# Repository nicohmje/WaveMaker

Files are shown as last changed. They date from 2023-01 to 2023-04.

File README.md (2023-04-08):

# Wave Generator for TECQUIPMENT FC80-5

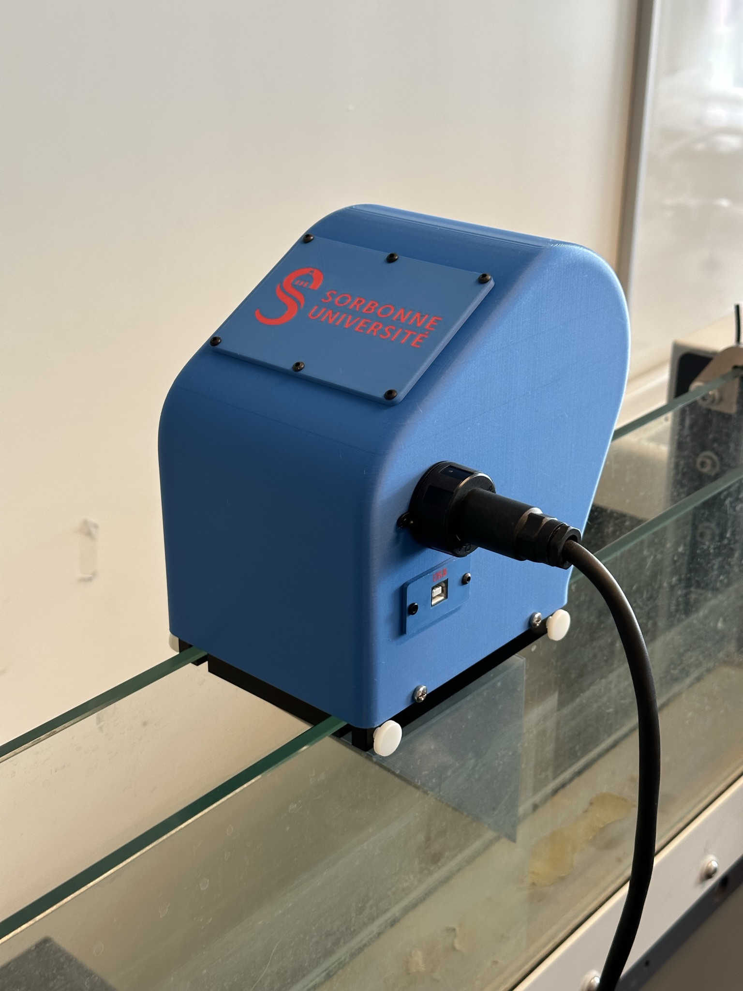
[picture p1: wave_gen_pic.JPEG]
the complete assembly


Add-on accessory designed for the TECQUIPMENT 5 meter Flow and sediment transport channel.

Intended use is to simulate various waves, including rogue waves, which are chosen by the user through a computer or a Raspberry Pi. 

Mechanical design inspired by the FC80N Wave Generator, but using two Dynamixel XL330-M288 servos and 3D printed parts. 

## Design / CAD  

First, the FC80-5 is measured, and the different parameters are defined. Chosen amplitude entails a 4 cm crankshaft, and the overall speed and responsiveness required makes the XL330-M288 the perfect motors for this use case. 

The existing FC80N is modeled, and the decision is made to keep the base and shaft bushing as they are machined aluminum which gives a nice heft that 3D printed parts wouldn't have. This significantly improves stability when displacing water. The use of the existing shaft bushing limits the shaft to a 20 cm diameter.

### 1. Bearings

The original design's joints use simple metal bushings for the pivots. The ensuing friction requires a lot of torque to smoothly overcome; this limits speed and requires a powerful motor with a significant amount of reduction (148:1 on the FC80N). Because Dynamixel Servos are to be used, all pivots will utilize ball bearings to smoothen motion and reduce motor load. 

Availability and price of bearings are a key factor in their selection; standard skateboard bearings can be found used for free in any skateboarding-related shop, and a smaller MR105-2RS bearing is used when the former don't fit. For the shaft linear motion, the original aluminum bushing provides a low enough friction coefficient that, with the right tolerance, the shaft slides smoothly back and forth with minimal side-to-side play.

### 2. 3D Printing

Every part is printed in PLA, as strength is not an issue at this scale. The shaft is printed vertically, which could lead to delamination of the layers in case of high tensile forces, but this has not been observed yet. If that were to be the case, a solution would be to print two shaft halves and glue them together. This would require support material for the joint-shaft inteface, which can increase friction because of poor surface finish. 

The plunger is printed with 10% infill to lighten it as much as possible. Possible upgrades include add-on surfaces to push the water more efficiently / in different ways. 

## Assembly

Every part fits together nicely. The U2D2 cables that go all the way to the servos don't have any routing guides, which could be added to the motor mount, as it must be ensured that they do not interfere with the crankshaft, which could lead to catastrophic tangles. 

The servos are held in place by screws, but a lack of the right sized screw prevents the crankshaft from being bolted to the motors; they are friction fitted, which works well but requires good alignment to work reliably. The plunger and shaft interface nicely with each other, with some light sanding done to the latter to improve surface finish.

## Equations

Inverse kinematics (wave -> motor pos) have not been established (yet). For future reference, these papers should help : 

B. Sun, C. Li, S. Yang, and H. Zhang, “A simplified method and numerical simulation for wedge-shaped plunger wavemaker,”

T. Mikkola, “Time accurate simulation of a plunger type wave maker using unstructured finite volume solver with surface tracking,”

C. Hirt and B. Nichols, “Volume of fluid (vof) method for the dynamics of free boundaries,”

B. Sun, C. Li, S. Yang, and H. Zhang, “A simplified method and numerical simulation for wedge-shaped plunger wavemaker,”

## Testing

TODO: Writeup about tests

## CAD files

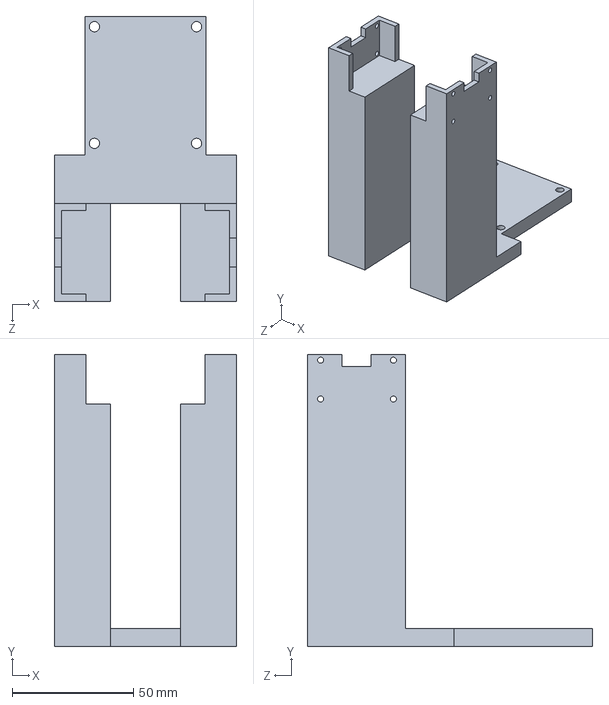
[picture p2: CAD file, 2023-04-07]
WaveMaker_CAD/WM_WaveMaker_MainFrame.SLDPRT
75.0 x 120.4 x 117.4 mm

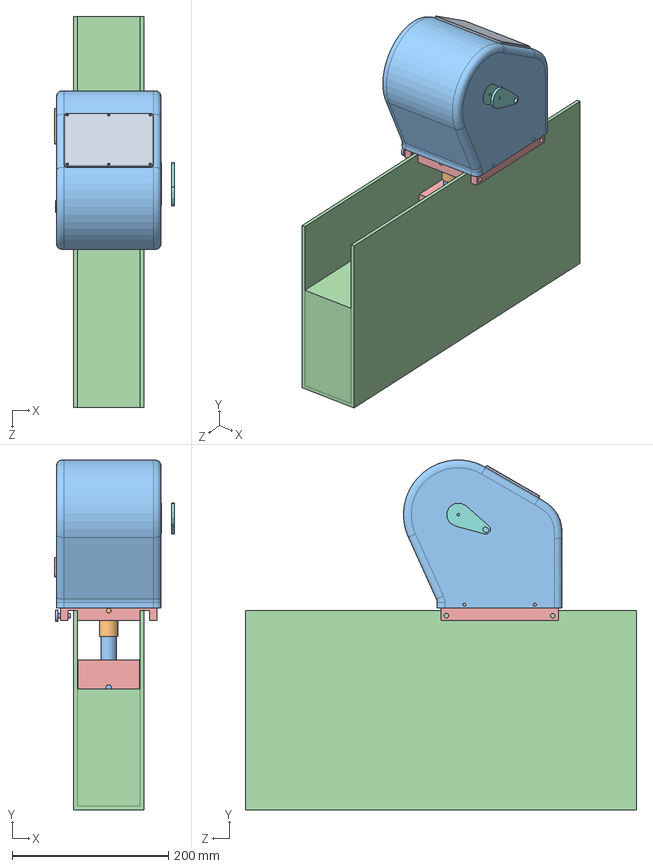
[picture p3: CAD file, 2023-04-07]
WaveMaker_CAD/WaveMaker_ASSEMBLY.SLDASM
153.7 x 447.4 x 500.0 mm
WM_WaveMaker_wave_flume
WM_WaveMaker_base
WM_WaveMaker_base_screw
WM_WaveMaker_MainFrame
WM_WaveMaker_Crankshaft_left_01 x 2
WM_WaveMaker_Joint_003
WM_WaveMaker_shaft_bushing
WM_WaveMaker_Piston_Shaft
WM_WaveMaker_Shaft
WM_WaveMaker_Plunger_002
WM_WaveMaker_Hull
WM_WaveMaker_USB-B_Mount
WM_WaveMaker_Hull_Lid
WM_WaveMaker_U2D2 Spacer x 4
WM_WaveMaker_XL330-M288T x 2
WM_WaveMaker_ROBOTIS_U2D2_Power_Hub_Board
WM_WaveMaker_SkateboardBearing
WM_WaveMaker_5_10_4

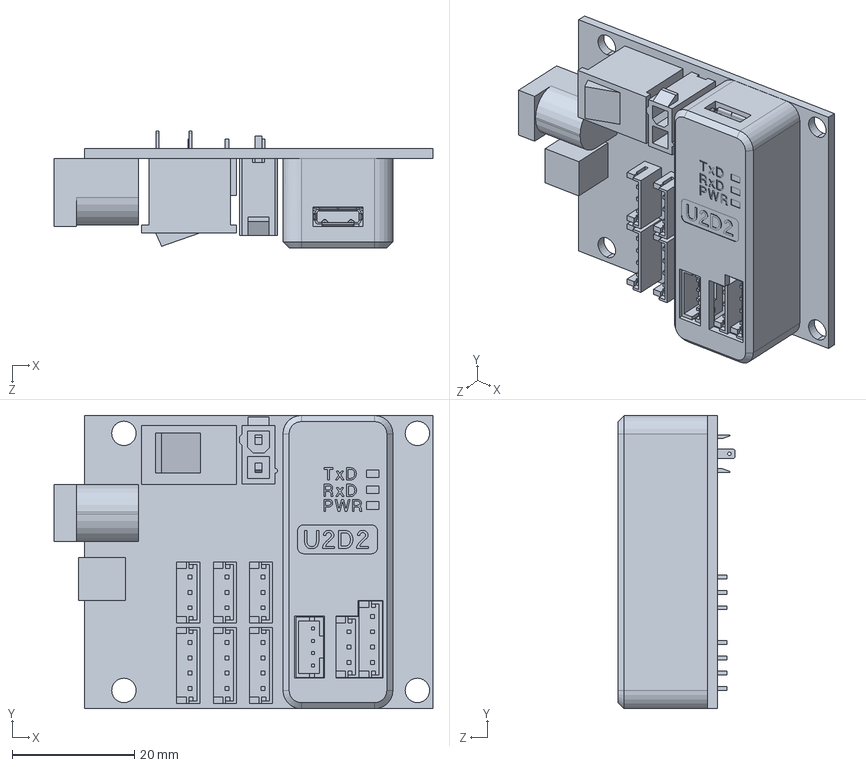
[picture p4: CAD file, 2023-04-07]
WaveMaker_CAD/WM_WaveMaker_ROBOTIS_U2D2_Power_Hub_Board.SLDPRT
62.0 x 48.0 x 19.1 mm

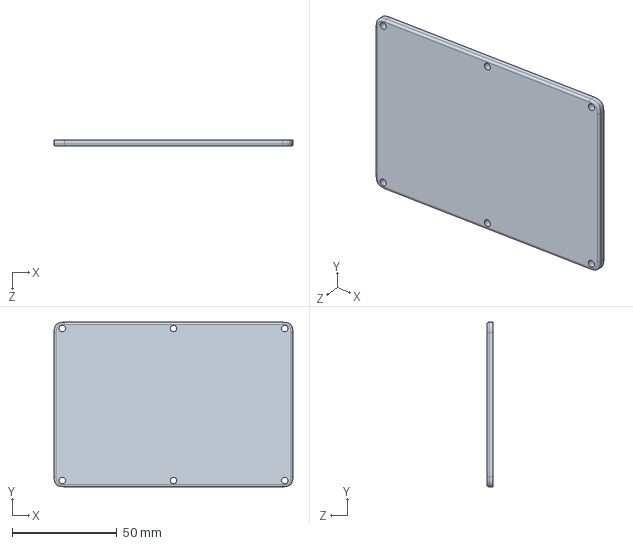
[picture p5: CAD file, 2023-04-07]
WaveMaker_CAD/WM_WaveMaker_Hull_Lid.SLDPRT
114.0 x 78.5 x 3.00 mm

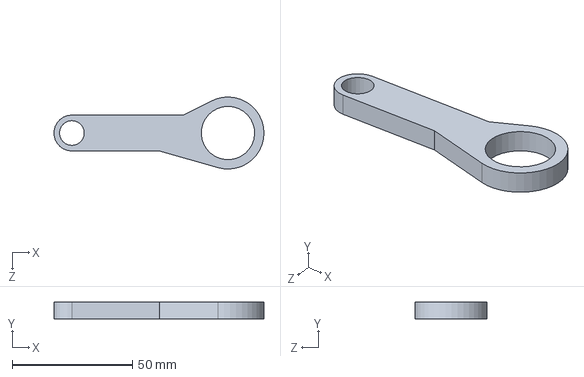
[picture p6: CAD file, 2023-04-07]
WaveMaker_CAD/WM_WaveMaker_Joint_003.SLDPRT
87.4 x 7.00 x 30.0 mm

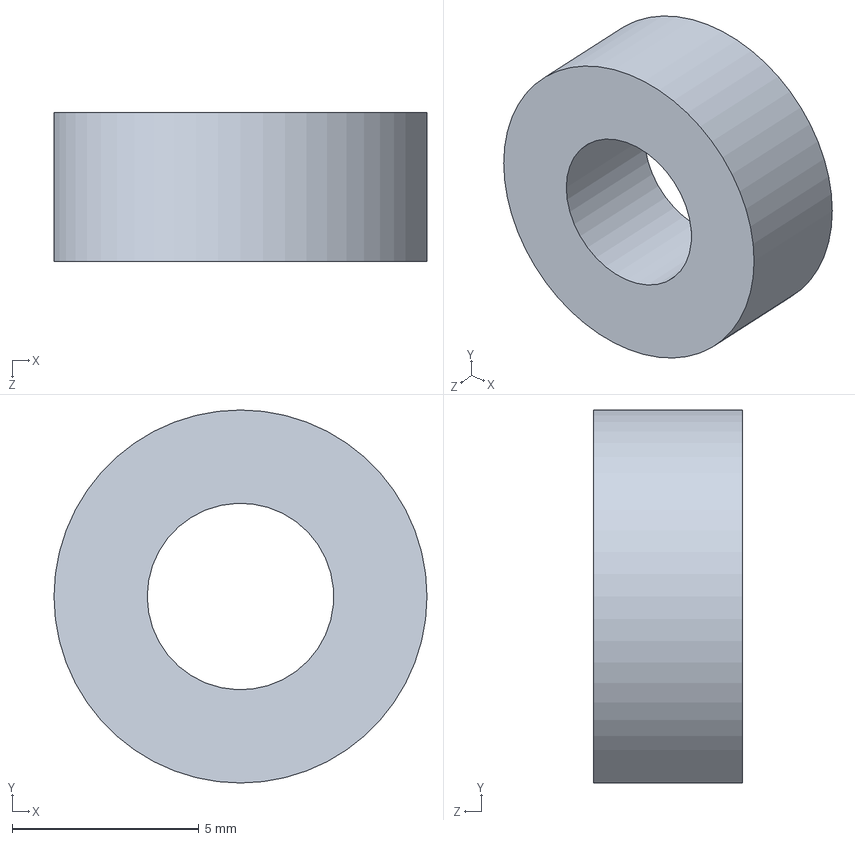
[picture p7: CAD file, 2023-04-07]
WaveMaker_CAD/WM_WaveMaker_5_10_4.SLDPRT
10.0 x 10.0 x 4.00 mm

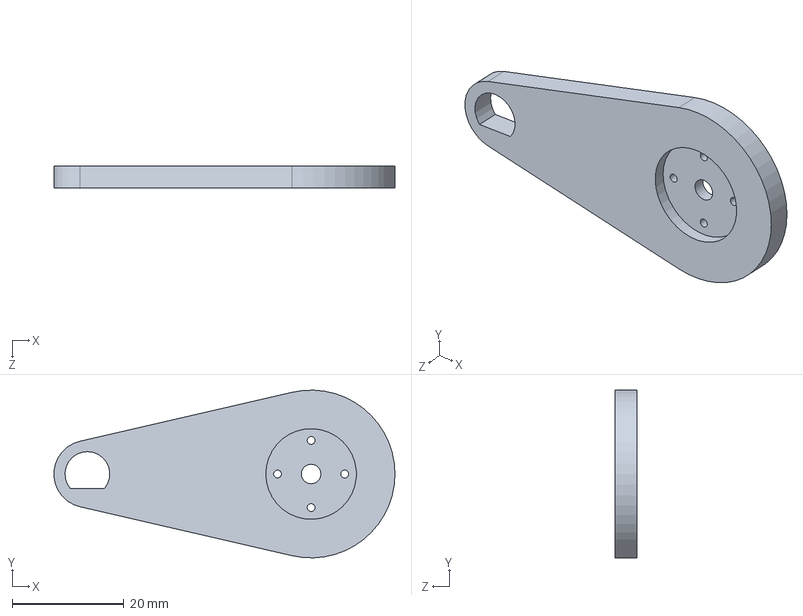
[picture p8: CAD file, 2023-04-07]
WaveMaker_CAD/WM_WaveMaker_Crankshaft_left_01.SLDPRT
61.0 x 30.0 x 4.00 mm

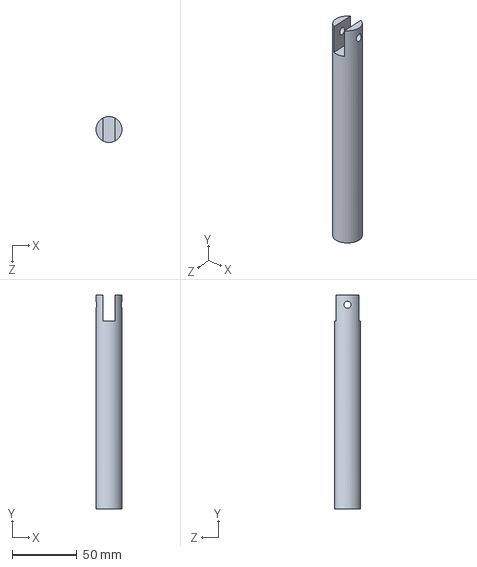
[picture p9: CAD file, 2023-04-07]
WaveMaker_CAD/WM_WaveMaker_Piston_Shaft.SLDPRT
20.0 x 165.0 x 20.0 mm

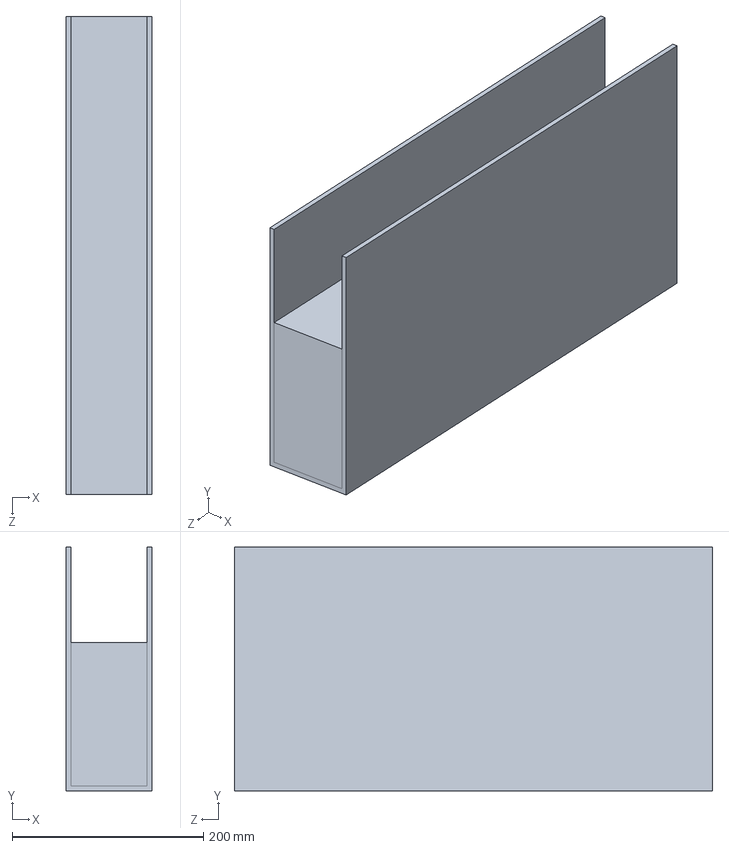
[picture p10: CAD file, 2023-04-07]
WaveMaker_CAD/WM_WaveMaker_wave_flume.SLDPRT
90.0 x 255.0 x 500.0 mm

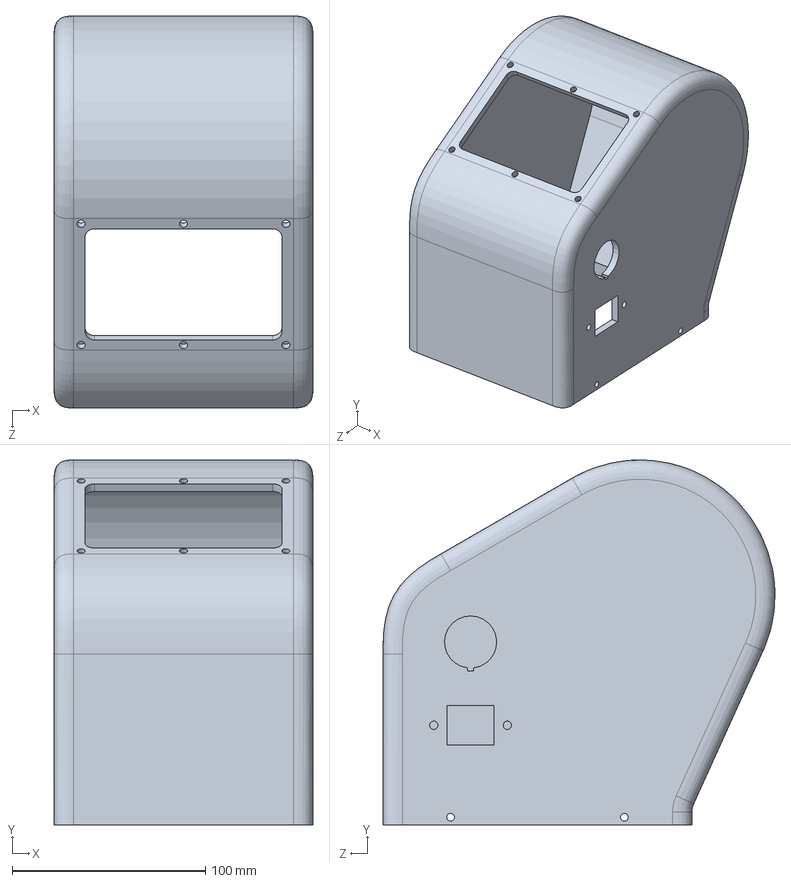
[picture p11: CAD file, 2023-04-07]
WaveMaker_CAD/WM_WaveMaker_Hull.SLDPRT
134.0 x 188.9 x 203.0 mm

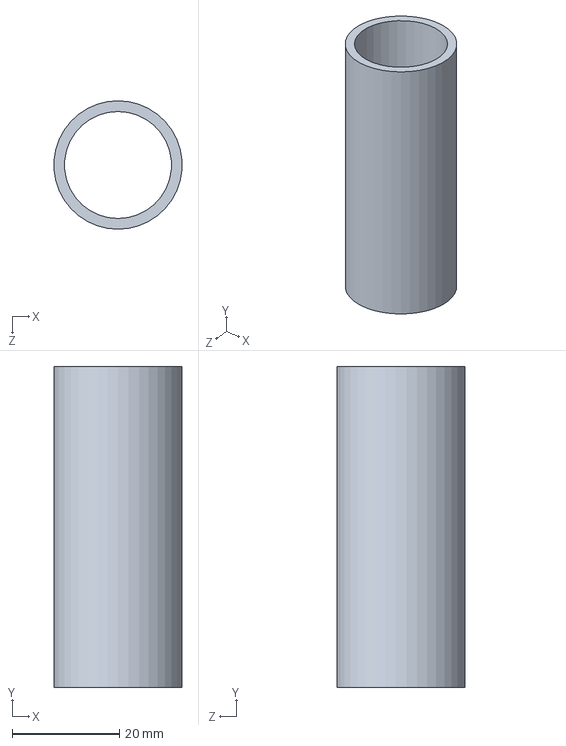
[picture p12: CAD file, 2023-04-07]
WaveMaker_CAD/WM_WaveMaker_shaft_bushing.SLDPRT
23.9 x 60.0 x 24.0 mm

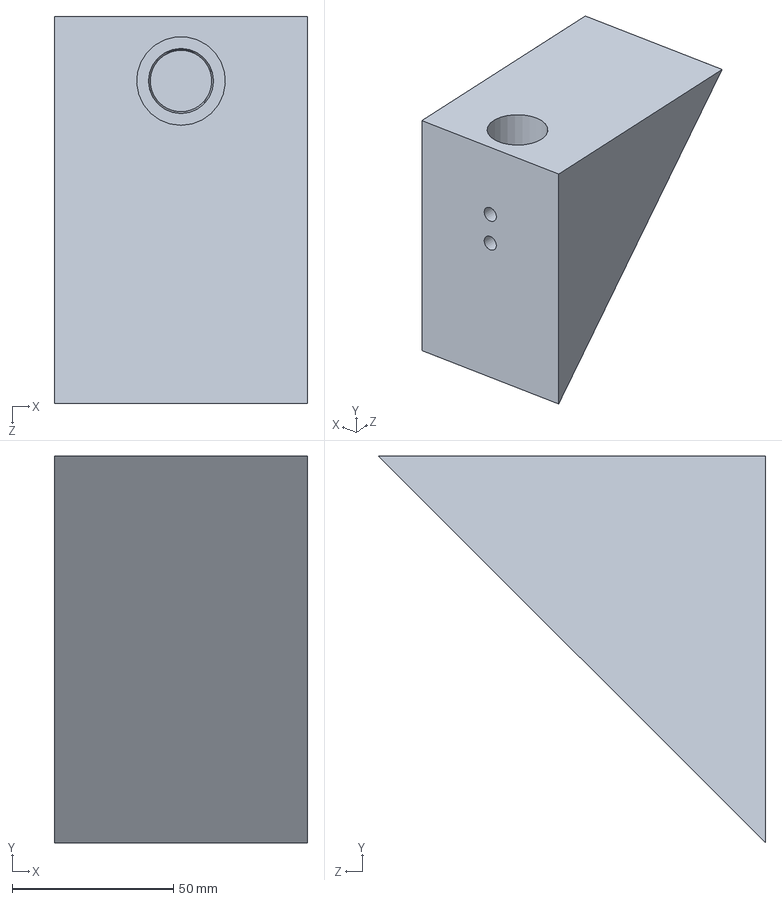
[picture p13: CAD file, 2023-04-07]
WaveMaker_CAD/WM_WaveMaker_Plunger_002.SLDPRT
78.5 x 120.0 x 120.0 mm

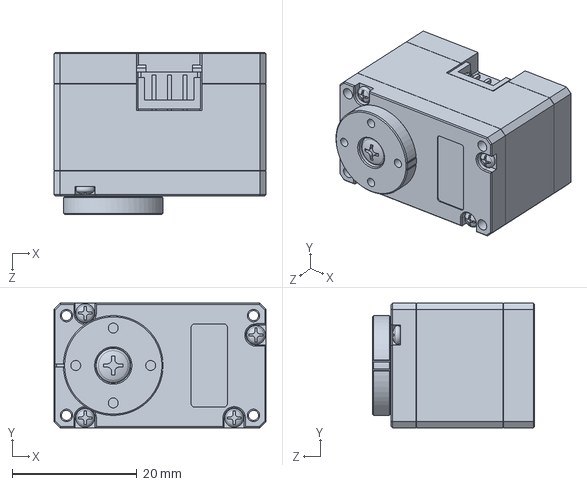
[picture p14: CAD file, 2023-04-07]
WaveMaker_CAD/WM_WaveMaker_XL330-M288T.SLDPRT
34.0 x 20.0 x 26.0 mm

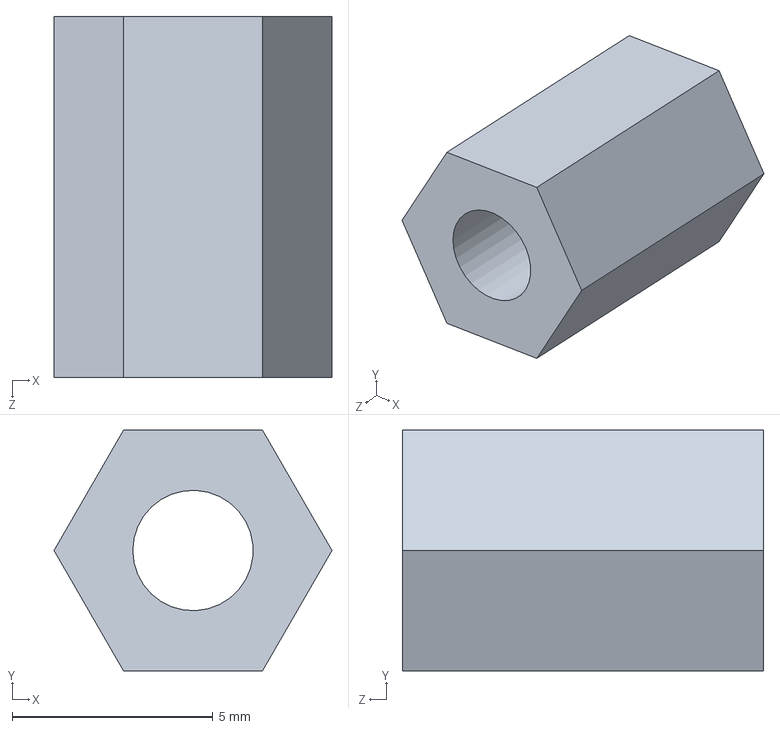
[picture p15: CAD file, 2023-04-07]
WaveMaker_CAD/WM_WaveMaker_U2D2 Spacer.SLDPRT
6.93 x 6.00 x 9.00 mm

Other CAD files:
WaveMaker_CAD/WM_WaveMaker_SkateboardBearing.SLDPRT
WaveMaker_CAD/WM_WaveMaker_Shaft.SLDPRT
WaveMaker_CAD/WM_WaveMaker_base.SLDPRT
WaveMaker_CAD/WM_WaveMaker_USB-B_Mount.SLDPRT
WaveMaker_CAD/WM_WaveMaker_base_screw.SLDPRT

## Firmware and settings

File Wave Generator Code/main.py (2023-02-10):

import tkinter as tk
from tkinter import ttk
from dynamixel_sdk import *
import time
import os
import numpy as np 

# Control table address
ADDR_PRO_TORQUE_ENABLE      = 64               # Control table address is different in Dynamixel model
ADDR_PRO_LED_RED            = 65
ADDR_PRO_GOAL_POSITION      = 116
ADDR_PRO_PRESENT_POSITION   = 132
ADDR_PRO_PROFILE_VELOCITY   = 112

# Data Byte Length
LEN_PRO_LED_RED             = 1
LEN_PRO_GOAL_POSITION       = 4
LEN_PRO_PRESENT_POSITION    = 4

# Protocol version
PROTOCOL_VERSION            = 2.0               # See which protocol version is used in the Dynamixel

# Default setting
DXL1_ID                     = 1                # Dynamixel#1 ID : 1
DXL2_ID                     = 2                # Dynamixel#1 ID : 2
BAUDRATE                    = 57600            # Dynamixel default baudrate : 57600
DEVICENAME                  = '/dev/tty.usbserial-FT763MZ5'    # Check which port is being used on your controller
                                                # ex) Windows: "COM1"   Linux: "/dev/ttyUSB0" Mac: "/dev/tty.usbserial-*"

TORQUE_ENABLE               = 1                # Value for enabling the torque
TORQUE_DISABLE              = 0                 # Value for disabling the torque
DXL_MINIMUM_POSITION_VALUE  = 100           # Dynamixel will rotate between this value
DXL_MAXIMUM_POSITION_VALUE  = 4000            # and this value (note that the Dynamixel would not move when the position value is out of movable range. Check e-manual about the range of the Dynamixel you use.)
DXL_MOVING_STATUS_THRESHOLD = 20 

POSITION_TOLERANCE          = 80            # This defines how close to the goal position the motor has to be for it to count as "reached"


os.system("clear")

print("-------------WAVE GENERATOR INTEFACE-------------")
print("|                                               |")
print("|                                               |")
print("|           Created by Nicolas Hammje           |")
print("|                                               |")
print("|                                               |")
print("|             www.nicolashammje.com             |")
print("|                                               |")
print("|              me@nicolashammje.com             |")
print("|                                               |")
print("|                                               |")
print("-------------------------------------------------")
print(" ")
print(" ")
print("Use the GUI to interface with the wave generator")
print("Output will be printed below this line:")


portHandler = PortHandler(DEVICENAME)

packetHandler = PacketHandler(PROTOCOL_VERSION)


#Open port to U2D2 
if portHandler.openPort():
    print("[INFO] Succeeded to open the port")
else:
    print("[ERROR] Failed to open the port")
    quit()

#Set the baudrate
if portHandler.setBaudRate(BAUDRATE):
    print("[INFO] Succeeded to change the baudrate")
else:
    print("[ERROR] Failed to change the baudrate")
    quit()


#Torque off 
dxl_comm_result, dxl_error = packetHandler.write1ByteTxRx(portHandler, DXL1_ID, ADDR_PRO_TORQUE_ENABLE, 0)
dxl_comm_result, dxl_error = packetHandler.write1ByteTxRx(portHandler, DXL2_ID, ADDR_PRO_TORQUE_ENABLE, 0)

#Operating mode : position
dxl_comm_result, dxl_error = packetHandler.write1ByteTxRx(portHandler, DXL1_ID, 11, 3)
dxl_comm_result, dxl_error = packetHandler.write1ByteTxRx(portHandler, DXL2_ID, 11, 3)

#Torque on
dxl_comm_result, dxl_error = packetHandler.write1ByteTxRx(portHandler, DXL1_ID, ADDR_PRO_TORQUE_ENABLE, 1)
dxl_comm_result, dxl_error = packetHandler.write1ByteTxRx(portHandler, DXL2_ID, ADDR_PRO_TORQUE_ENABLE, 1)




#This sanitizes the inputs to ensure that the trajectory is valid
def check_angles():
    theta = float(theta_slider.get())
    theta2 = float(theta2_slider.get())

    goal_pos = 3072 - int((2048. / np.pi) * theta2) #Goal pos is straight down plus theta1
    top_pos = 1024+ int((2048. / np.pi) * theta) #Top pos is straight up minus theta2
    if goal_pos<top_pos:
        print("[ERROR] User inputted angles are not valid. Please check that your units are radians, and that the start position is above the end position.")
        return
    if theta>2*np.pi:
        print("[ERROR] Start angle is too big. Check that your units are radians")
        return  
    if theta2>2*np.pi:
        print("[ERROR] End angle is too big. Check that your units are radians")
        return  
    launch_wave()


#The main function  
def launch_wave(): 

    debug = bool(debug_toggle.get()) #Debug toggle, outputs more info to the console
    num = int(wave_number.get()) #Number of waves to send
    delay = int(wave_delay.get()) #Delay between the diff waves. The plunger will wait in the bottom position
    period = float(omega_entry.get()) #Period of wave
    theta = float(theta_slider.get()) #This defines the starting angle, relative to vertical high
    theta2 = float(theta2_slider.get()) #This defines the end angle, relative to vertical low


    omega  = int(((np.pi - theta - theta2) / period)  * 15 / 0.18 )
    if (omega > 32767):
        omega = 0 
    #Profile Velocity 
    dxl_comm_result, dxl_error = packetHandler.write4ByteTxRx(portHandler, DXL1_ID, ADDR_PRO_PROFILE_VELOCITY, 200)

    goal_pos = 3072 - int((2048. / np.pi) * theta2) #Goal pos is straight up minus theta1
    top_pos = 1024+ int((2048. / np.pi) * theta) #Bottom pos is straight down plus theta2

    print("[INFO] Moving to starting position ..")
    dxl_comm_result, dxl_error = packetHandler.write4ByteTxRx(portHandler, DXL1_ID, ADDR_PRO_GOAL_POSITION, top_pos)
    pos = 0
    count = 0 
    while pos < top_pos - POSITION_TOLERANCE  and (count < 1000): 
        pos, result, error = packetHandler.read4ByteTxRx(portHandler, DXL2_ID, ADDR_PRO_PRESENT_POSITION)
        if debug:
            print("[DEBUG]", pos)
        count = count + 1

    time.sleep(1)
    dxl_comm_result, dxl_error = packetHandler.write4ByteTxRx(portHandler, DXL1_ID, ADDR_PRO_PROFILE_VELOCITY, omega)
    print("[INFO]", "Omega", omega)

    #Position = 2048 * 2 
    #3072 = top <-> 1024 = bottom
    print("[INFO] Moving from", (top_pos-1024)*(np.pi/2048), "to", (goal_pos-1024)*(np.pi/2048))
    print("[INFO] Start angle:", theta)
    print("[INFO] End angle:", theta2)

    if bwave.get():
        print("[INFO] Big wave is enabled")
    else:
        print("[INFO] Big wave is disabled")


    i = 1
    while i <= num: #Launch 'num' waves
        print("[INFO] Launching wave", i)
        completed = False
        failure, completed = move_motors(goal_pos, top_pos)
        while (completed == False):
            print("waiting")
            time.sleep(0.05)
        if (delay>0):
            print("[INFO] Delaying :", delay)
            time.sleep(delay)
        if (failure):
            print("[ERROR] Failed to execute trajectory. Check theta1 and theta2 for possible errors.")
            return
        i = i + 1

    if int(bwave.get()) == 1: #Launch big wave if enabled
        dxl_comm_result, dxl_error = packetHandler.write4ByteTxRx(portHandler, DXL1_ID, ADDR_PRO_PROFILE_VELOCITY, 0)
        move_motors(3072, 1024) 
        print("[INFO] Launching Big wave")

    print("[INFO] Returning to top in 2 seconds..")
    time.sleep(2) #After 2 seconds, go back to resting position which is at the top
    dxl_comm_result, dxl_error = packetHandler.write4ByteTxRx(portHandler, DXL1_ID, ADDR_PRO_PROFILE_VELOCITY, 150)
    dxl_comm_result, dxl_error = packetHandler.write4ByteTxRx(portHandler, DXL1_ID, ADDR_PRO_GOAL_POSITION, 1024)
    print("[INFO] Successfully launched", num, "wave.s")


#Moves the motors back and forth one period, resulting in a single wave. 
def move_motors(goal_pos, top_pos):
    debug = bool(debug_toggle.get())
    period = float(omega_entry.get())
    
    if (goal_pos < top_pos):
        print("[ERROR] The bottom position is above the top position, can't move")
        return True, True

    #Move to top starting position
    dxl_comm_result, dxl_error = packetHandler.write4ByteTxRx(portHandler, DXL1_ID, ADDR_PRO_GOAL_POSITION, top_pos)

    pos = 5000 #This is just so that the while loop engages. Could also set it to the actual position.
    count = 0 
    while (pos > (top_pos + POSITION_TOLERANCE))  and (count < 200): #Tolerance and loop limit
        pos, result, error = packetHandler.read4ByteTxRx(portHandler, DXL2_ID, ADDR_PRO_PRESENT_POSITION)
        if debug:
            print("[DEBUG]",top_pos, pos, count)
        count = count + 1
        time.sleep(period/400)

    #Move to bottom
    dxl_comm_result, dxl_error = packetHandler.write4ByteTxRx(portHandler, DXL1_ID, ADDR_PRO_GOAL_POSITION, goal_pos)

    pos = 0 
    count = 0 
    while (pos < (goal_pos - POSITION_TOLERANCE)) and (count < 200): #Tolerance and loop limit
        pos, result, error = packetHandler.read4ByteTxRx(portHandler, DXL2_ID, ADDR_PRO_PRESENT_POSITION)
        if debug:  
            print("[DEBUG]",goal_pos, pos, count)
            time.sleep(period/400)
        count = count + 1
    return False, True



#--------------------GUI--------------------
#Everything below this is just GUI configuration 


# root window
root = tk.Tk()
root.geometry('400x183')
root.resizable(False, True)
root.title('Wave Generator')


root.columnconfigure(0, weight=1)
root.columnconfigure(1, weight=3)

# slider current value
omega_val = tk.DoubleVar()


# label for the slider
speed_slider = ttk.Label(
    root,
    text='Period (s)'
)

speed_slider.grid(
    column=0,
    row=0,
    sticky='we'
)

# slider current value
theta = tk.DoubleVar()


# label for the slider
theta_slider_label = ttk.Label(
    root,
    text='Start angle (rad)'
)

#position in grid
theta_slider_label.grid(
    column=0,
    row=1,
    sticky='we'
)

theta2_slider_label = ttk.Label(
    root,
    text='End angle (rad)'
)

theta2_slider_label.grid(
    column=0,
    row=2,
    sticky='we'
)

delay_label = ttk.Label(
    root,
    text='Delay between waves (s)'
)

delay_label.grid(
    column=0,
    row=3,
    sticky='we'
)

number_label = ttk.Label(
    root,
    text='Number of waves'
)

number_label.grid(
    column=0,
    row=4,
    sticky='we'
)

wave_number = ttk.Entry(
    root,
)

wave_delay = ttk.Entry(
    root
)

wave_delay.grid(
    column = 1,
    row = 3,
    sticky='we'
)

wave_number.grid(
    column = 1,
    row = 4,
    sticky='we'
)



#Initial speed is set to 600, but this will //
#get reduced by a factor of 0.25 before being// 
#parsed to the motors. 




theta_slider = ttk.Entry(
    root,
)

theta_slider.grid(
    column=1,
    row=1,
    sticky='we'
)

theta2 = tk.DoubleVar()
theta2_slider = ttk.Entry(
    root,

)

theta2_slider.grid(
    column=1,
    row=2,
    sticky='we'
)

omega_val = tk.DoubleVar()
omega_entry = ttk.Entry(
    root,

)
omega_entry.grid(
    column=1,
    row=0,
    sticky='we'
)


bwave = tk.StringVar()

big_wave = ttk.Checkbutton(
    root,
    text="Add a big wave at the end?",
    variable=bwave
)

bwave.set(0) #Default disabled

big_wave.grid(
    column=1,
    row=6,
    sticky='we'
)

debug_toggle = tk.StringVar()

debug_check = ttk.Checkbutton(
    root,
    text="Debug mode",
    variable=debug_toggle
)

debug_check.grid(
    column=1,
    row=7,
    sticky='we'
)


theta_slider.insert("end", "0")
theta2_slider.insert("end", "0")
wave_delay.insert("end",'0')
wave_number.insert("end", '1')

launch_button = ttk.Button(
    root,
    text="LAUNCH",
    command=check_angles,
)

launch_button.grid(
    column=1,
    row=5,
    sticky='we'
)



#--------------------END GUI--------------------




root.mainloop()

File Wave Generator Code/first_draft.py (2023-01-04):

from dynamixel_sdk import *
import time

# Control table address
ADDR_PRO_TORQUE_ENABLE      = 64               # Control table address is different in Dynamixel model
ADDR_PRO_LED_RED            = 65
ADDR_PRO_GOAL_POSITION      = 116
ADDR_PRO_PRESENT_POSITION   = 132

# Data Byte Length
LEN_PRO_LED_RED             = 1
LEN_PRO_GOAL_POSITION       = 4
LEN_PRO_PRESENT_POSITION    = 4

# Protocol version
PROTOCOL_VERSION            = 2.0               # See which protocol version is used in the Dynamixel

# Default setting
DXL1_ID                     = 1                 # Dynamixel#1 ID : 1
DXL2_ID                     = 2                # Dynamixel#1 ID : 2
BAUDRATE                    = 57600             # Dynamixel default baudrate : 57600
DEVICENAME                  = '/dev/tty.usbserial-FT6Z5R6J'    # Check which port is being used on your controller
                                                # ex) Windows: "COM1"   Linux: "/dev/ttyUSB0" Mac: "/dev/tty.usbserial-*"

TORQUE_ENABLE               = 1                # Value for enabling the torque
TORQUE_DISABLE              = 0                 # Value for disabling the torque
DXL_MINIMUM_POSITION_VALUE  = 100           # Dynamixel will rotate between this value
DXL_MAXIMUM_POSITION_VALUE  = 4000            # and this value (note that the Dynamixel would not move when the position value is out of movable range. Check e-manual about the range of the Dynamixel you use.)
DXL_MOVING_STATUS_THRESHOLD = 20 

portHandler = PortHandler(DEVICENAME)

packetHandler = PacketHandler(PROTOCOL_VERSION)

if portHandler.openPort():
    print("Succeeded to open the port")
else:
    print("Failed to open the port")
    print("Press any key to terminate...")
    quit()

if portHandler.setBaudRate(BAUDRATE):
    print("Succeeded to change the baudrate")
else:
    print("Failed to change the baudrate")
    print("Press any key to terminate...")
    quit()

#1 = velocity and 3 = position 
dxl_comm_result, dxl_error = packetHandler.write2ByteTxRx(portHandler, DXL1_ID, 11, 3)
dxl_comm_result, dxl_error = packetHandler.write2ByteTxRx(portHandler, DXL2_ID, 11, 3)

#Torque enable
dxl_comm_result, dxl_error = packetHandler.write1ByteTxRx(portHandler, DXL1_ID, 64, 1)
dxl_comm_result, dxl_error = packetHandler.write1ByteTxRx(portHandler, DXL2_ID, 64, 1)

#LED enable
dxl_comm_result, dxl_error = packetHandler.write1ByteTxRx(portHandler, DXL1_ID, 65, 1)
dxl_comm_result, dxl_error = packetHandler.write1ByteTxRx(portHandler, DXL2_ID, 65, 1)

time.sleep(2)
i=1
while i<3:
#Read position
    pos1, dxl_comm_result, dxl_error = packetHandler.read4ByteTxRx(portHandler, DXL1_ID, 132)
    pos2, dxl_comm_result, dxl_error = packetHandler.read4ByteTxRx(portHandler, DXL2_ID, 132)
    print("pos 1:", pos1, "pos 2:", pos2 )
    i = i + 1 
    time.sleep(1)

#Give position
dxl_comm_result, dxl_error = packetHandler.read4ByteTxRx(portHandler, DXL1_ID, 116, 1560)
dxl_comm_result, dxl_error = packetHandler.4ByteTxRx(portHandler, DXL2_ID, 116, 2326)

time.sleep(3)

dxl_comm_result, dxl_error = packetHandler.write4ByteTxRx(portHandler, DXL1_ID, 116, 3032)
dxl_comm_result, dxl_error = packetHandler.write4ByteTxRx(portHandler, DXL2_ID, 116, 854)

time.sleep(3)

dxl_comm_result, dxl_error = packetHandler.write4ByteTxRx(portHandler, DXL1_ID, 104, 0)
dxl_comm_result, dxl_error = packetHandler.write4ByteTxRx(portHandler, DXL2_ID, 104, 0)


dxl_comm_result, dxl_error = packetHandler.write1ByteTxRx(portHandler, DXL1_ID, 64, 0)
dxl_comm_result, dxl_error = packetHandler.write1ByteTxRx(portHandler, DXL2_ID, 64, 0)

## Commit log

2022-11-25 first file dump
    NOTE: Assemblies might require a manual pathing to the diff files due to change of folder structure during cloud upload
    [330mount_proto1.SLDPRT, 330mount_proto2.SLDPRT, Assembly_002.SLDASM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]
2023-02-10 added references
    Added references to papers for possible future inverse kinematics computation
2023-04-07 Final Files upload
    updated hull design and organized files
    [WM_WaveMaker_5_10_4.SLDPRT, WM_WaveMaker_Crankshaft_left_01.SLDPRT, WM_WaveMaker_Hull.SLDPRT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]
